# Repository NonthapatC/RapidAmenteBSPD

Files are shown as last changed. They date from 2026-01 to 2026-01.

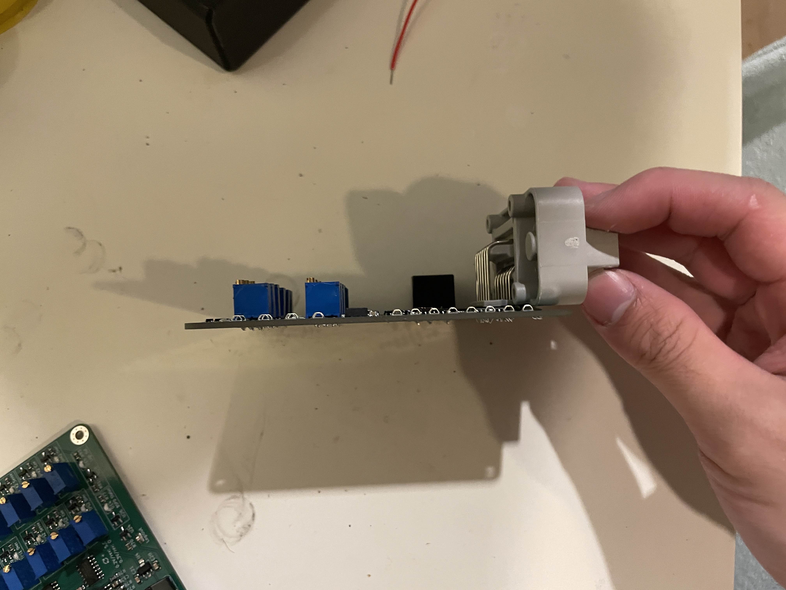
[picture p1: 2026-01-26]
----STEP_FILE----OPEN _PIC----/IMG_8208.jpg

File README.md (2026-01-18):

BSPD Logic;
TPS1 sense = TS1
TPS1 con = TC1
TPS1 over = TO1

TPS2 sense = TS2
TPS2 con = TC2
TPS2 over = TO2

BRK1 sense = BS1
BRK1 con = BC1
BRK1 over = BO1

BRK2 sense = BS2
BRK2 con = BC2
BRK2 over = BO2

(TS1+TS2)(BS1+BS2) -> 1000ms delay -> A

[(TC1)(TC2)(TO1+TO2)’(BC1)(BC2)(BO1+BO2)’]’ -> 100ms delay -> B

Final Logic; A+B -> latch R pin

Characteristic;
Normal:
BSPD status = 0v
BSPD status led = off
Latch R1/LogiOut led = off
Relay = com connected to NO; disconnected from NC

trip:
BSPD status = 12v
BSPD status led = on
Latch R1/LogiOut = on when trip condition satisfied
Relay = com connected to NC; disconnected from NO

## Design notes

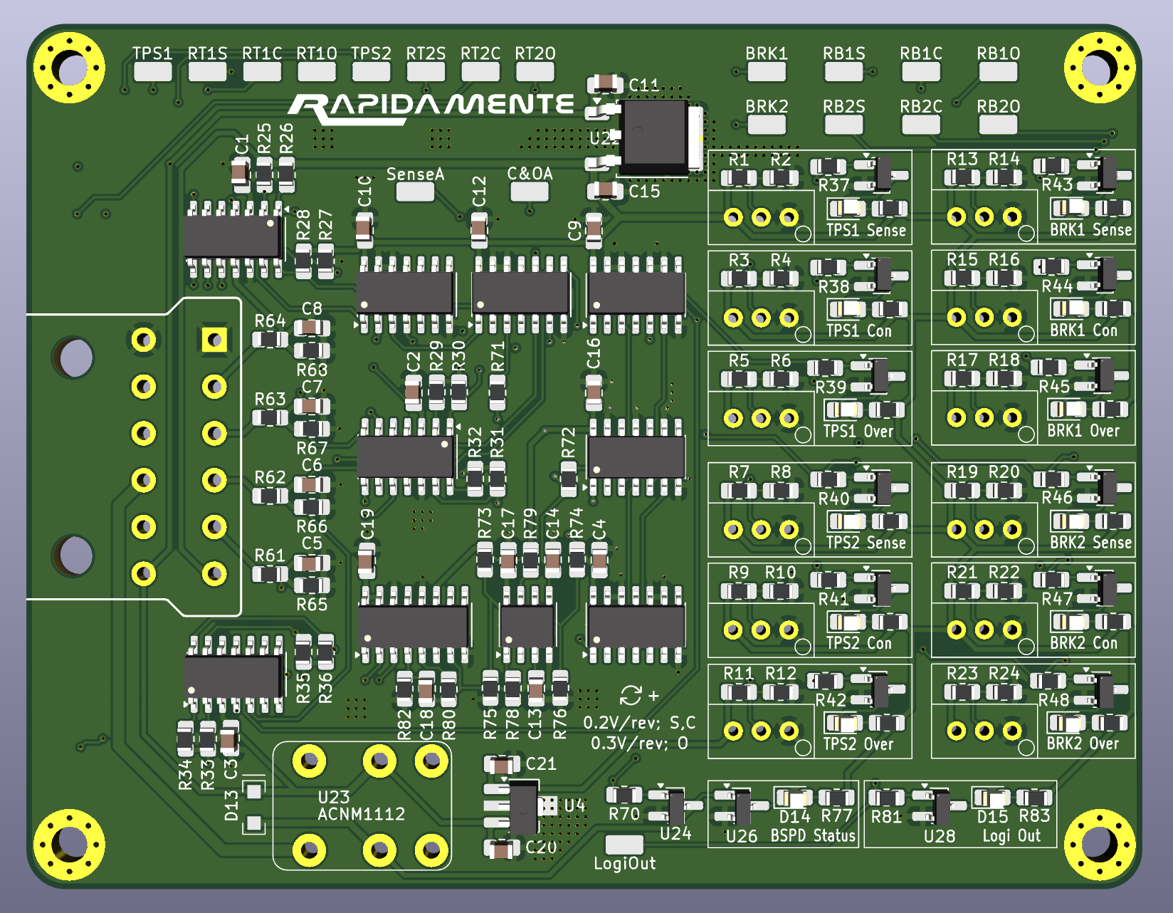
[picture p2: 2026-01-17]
Screenshot 2569-01-17 at 16.56.03.png

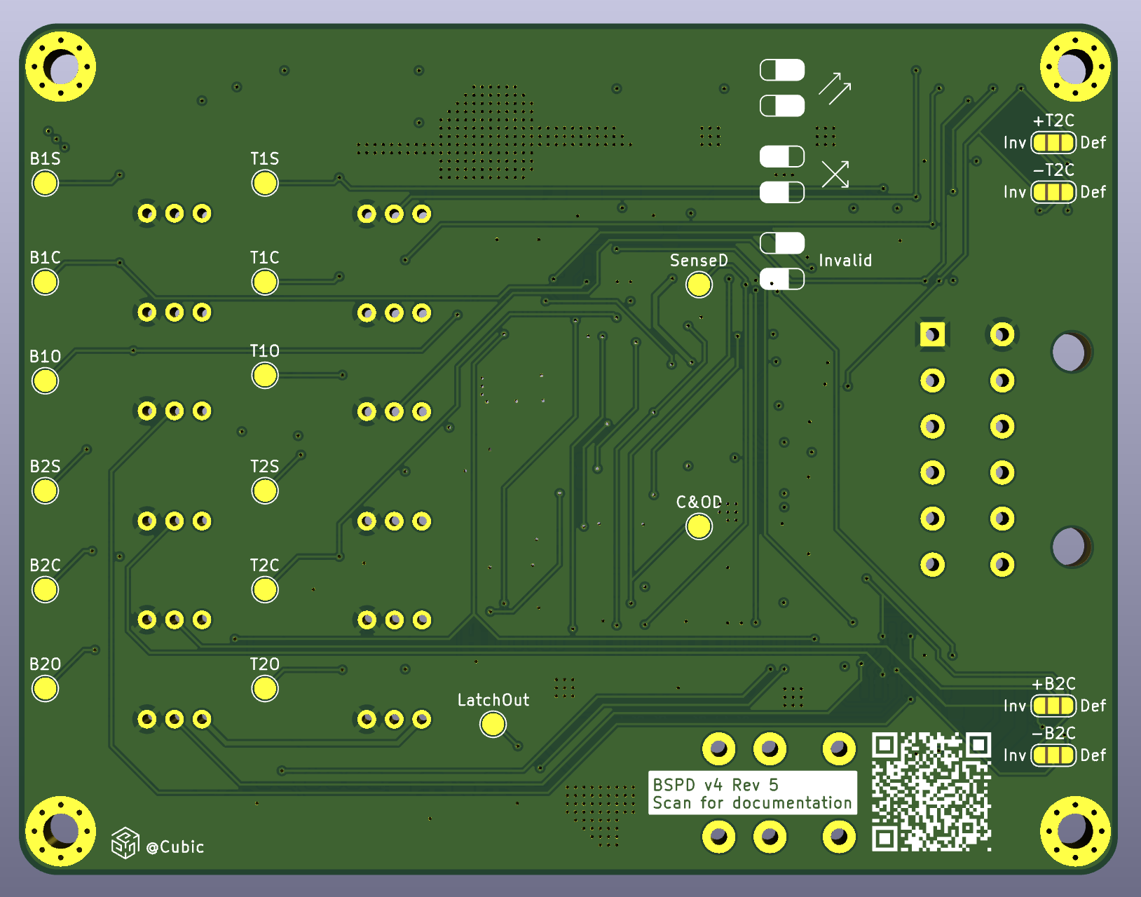
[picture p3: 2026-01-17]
Screenshot 2569-01-17 at 16.56.17.png

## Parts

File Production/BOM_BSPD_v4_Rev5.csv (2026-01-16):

Reference | Qty | Value | LCSC part number | Datasheet
C1,C2,C3,C4,C9,C10,C12,C15,C16,C17,C19,C21 | 12 | C0.1uF | C1711 | https://www.lcsc.com/product-detail/C1711.html?s_z=n_C1711
C5,C6,C7,C8 | 4 | C10nF | C1710 | https://www.lcsc.com/product-detail/C1710.html?s_z=n_C1710
C11,C20 | 2 | C0.33uF | C73142 | https://www.lcsc.com/product-detail/C73142.html?s_z=n_C73142
C13,C14,C18 | 3 | C10uF | C15850 | https://www.lcsc.com/product-detail/C15850.html?s_z=n_C15850
D1,D4,D7,D10 | 4 | YLED | C965814 | https://www.lcsc.com/product-detail/C965814.html
D2,D5,D8,D11 | 4 | GLED | C2986041 | https://www.lcsc.com/product-detail/C2986041.html
D3,D6,D9,D12,D14,D15 | 6 | RLED | C965812 | https://www.lcsc.com/product-detail/C965812.html?s_z=n_C965812
D13 | 1 | CRH01 | C2847411 | https://www.lcsc.com/product-detail/C2847411.html
J1 | 1 | DTM13-12PA | C17510017 | https://www.lcsc.com/product-detail/C17510017.html?s_z=n_dtm13-12PA
R25,R26,R27,R28,R29,R30,R31,R32,R33,R34,R35,R36,R65,R66,R67,R68,R73,R74,R78,R79,R80,R82 | 22 | R10K | C84376 | https://www.lcsc.com/product-detail/C84376.html?s_z=n_C84376
R37,R38,R39,R40,R41,R42,R43,R44,R45,R46,R47,R48,R81 | 13 | R150 | C17471 | https://www.lcsc.com/product-detail/C17471.html?s_z=n_C17471
R49,R51,R52,R54,R55,R57,R58,R60,R77,R83 | 10 | R200 | C2933534 | https://www.lcsc.com/product-detail/C2933534.html
R50,R53,R56,R59 | 4 | R82 | C2907287 | https://www.lcsc.com/product-detail/C2907287.html
R61,R62,R63,R64 | 4 | R1K | C17513 | https://www.lcsc.com/product-detail/C17513.html
R70 | 1 | R500 | C2828857 | https://www.lcsc.com/product-detail/C2828857.html?s_z=n_C2828857
R71 | 1 | R68K | C17801 | https://www.lcsc.com/product-detail/C17801.html?s_z=n_C17801
R72 | 1 | R6.8K | C114550 | https://www.lcsc.com/product-detail/C114550.html?s_z=n_C114550
R75,R76 | 2 | R22K | C114565 | https://www.lcsc.com/product-detail/C114565.html?s_z=n_C114565
RV1,RV2,RV3,RV4,RV5,RV6,RV7,RV8,RV9,RV10,RV11,RV12 | 12 | R_Potentiometer_Trim | C118954 | https://www.lcsc.com/product-detail/C118954.html?s_z=n_C118954
TP1,TP2,TP3,TP4,TP5,TP6,TP7,TP8,TP9,TP10,TP11,TP12,TP13,TP14,TP15,TP16,TP29,TP30,TP33 | 19 | TestHook | C5199798 | https://www.lcsc.com/product-detail/C5199798.html?s_z=n_C5199798
U1,U2,U3 | 3 | LM339 | C71036 | https://www.lcsc.com/product-detail/C71036.html?s_z=n_st
U4 | 1 | 78L08MG-AB3-R | C75495 | https://www.lcsc.com/product-detail/C75495.html
U5,U6,U7,U8,U9,U10,U11,U12,U13,U14,U15,U16,U26,U28 | 14 | 2N7002 | C65189 | https://www.lcsc.com/product-detail/C65189.html
U17 | 1 | 74HC08D | C5593 | https://www.lcsc.com/product-detail/C5593.html?s_z=n_74HC08
U18 | 1 | 74HC21D | C5617 | https://www.lcsc.com/product-detail/C5617.html
U19,U21 | 2 | 74HC32D | C5632 | https://www.lcsc.com/product-detail/C5632.html?s_z=n_C5632
U20 | 1 | 74HC04 | C5590 | https://www.lcsc.com/product-detail/C5590.html?s_z=n_C5590
U22 | 1 | L78M05ABDT-TR | C58069 | https://www.lcsc.com/product-detail/C58069.html
U23 | 1 | ACNM1112 | C5355536 | https://www.lcsc.com/product-detail/C5355536.html
U24 | 1 | IRLML2502TRPBF | C2589 | https://www.lcsc.com/product-detail/C2589.html
U25 | 1 | CD4043BDR | C40131 | https://www.lcsc.com/product-detail/C40131.html?s_z=n_CD4043B
U27 | 1 | LM393 | C32901 | https://www.lcsc.com/product-detail/C32901.html?s_z=n_C32901

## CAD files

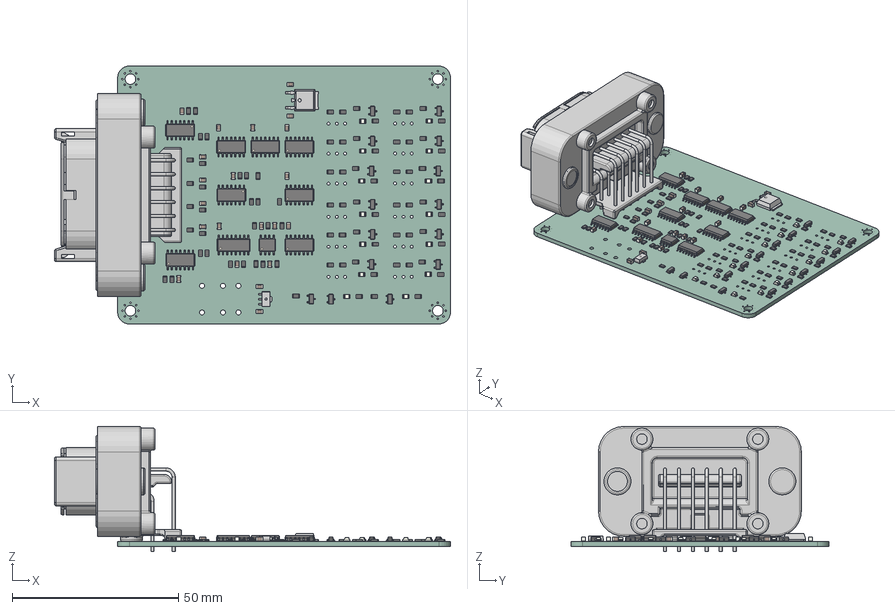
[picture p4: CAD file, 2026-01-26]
----STEP_FILE----OPEN _PIC----/27JAN_BSPD v4 Rev 5.step
119.0 x 77.5 x 37.6 mm
R_0805_2012Metric x 82
LED_0805_2012Metric x 14
SOIC-14_3.9x8.7mm_P1.27mm x 8
27JAN_BSPD v4 Rev 5 1.7.1
C_0805_2012Metric x 21
SOT-23 x 15
SOIC-8_3.9x4.9mm_P1.27mm
27JAN_BSPD v4 Rev 5 1.90.1
SOIC-16_3.9x9.9mm_P1.27mm
BSPD v4 Rev 5_PCB
C-DTM13-12PA

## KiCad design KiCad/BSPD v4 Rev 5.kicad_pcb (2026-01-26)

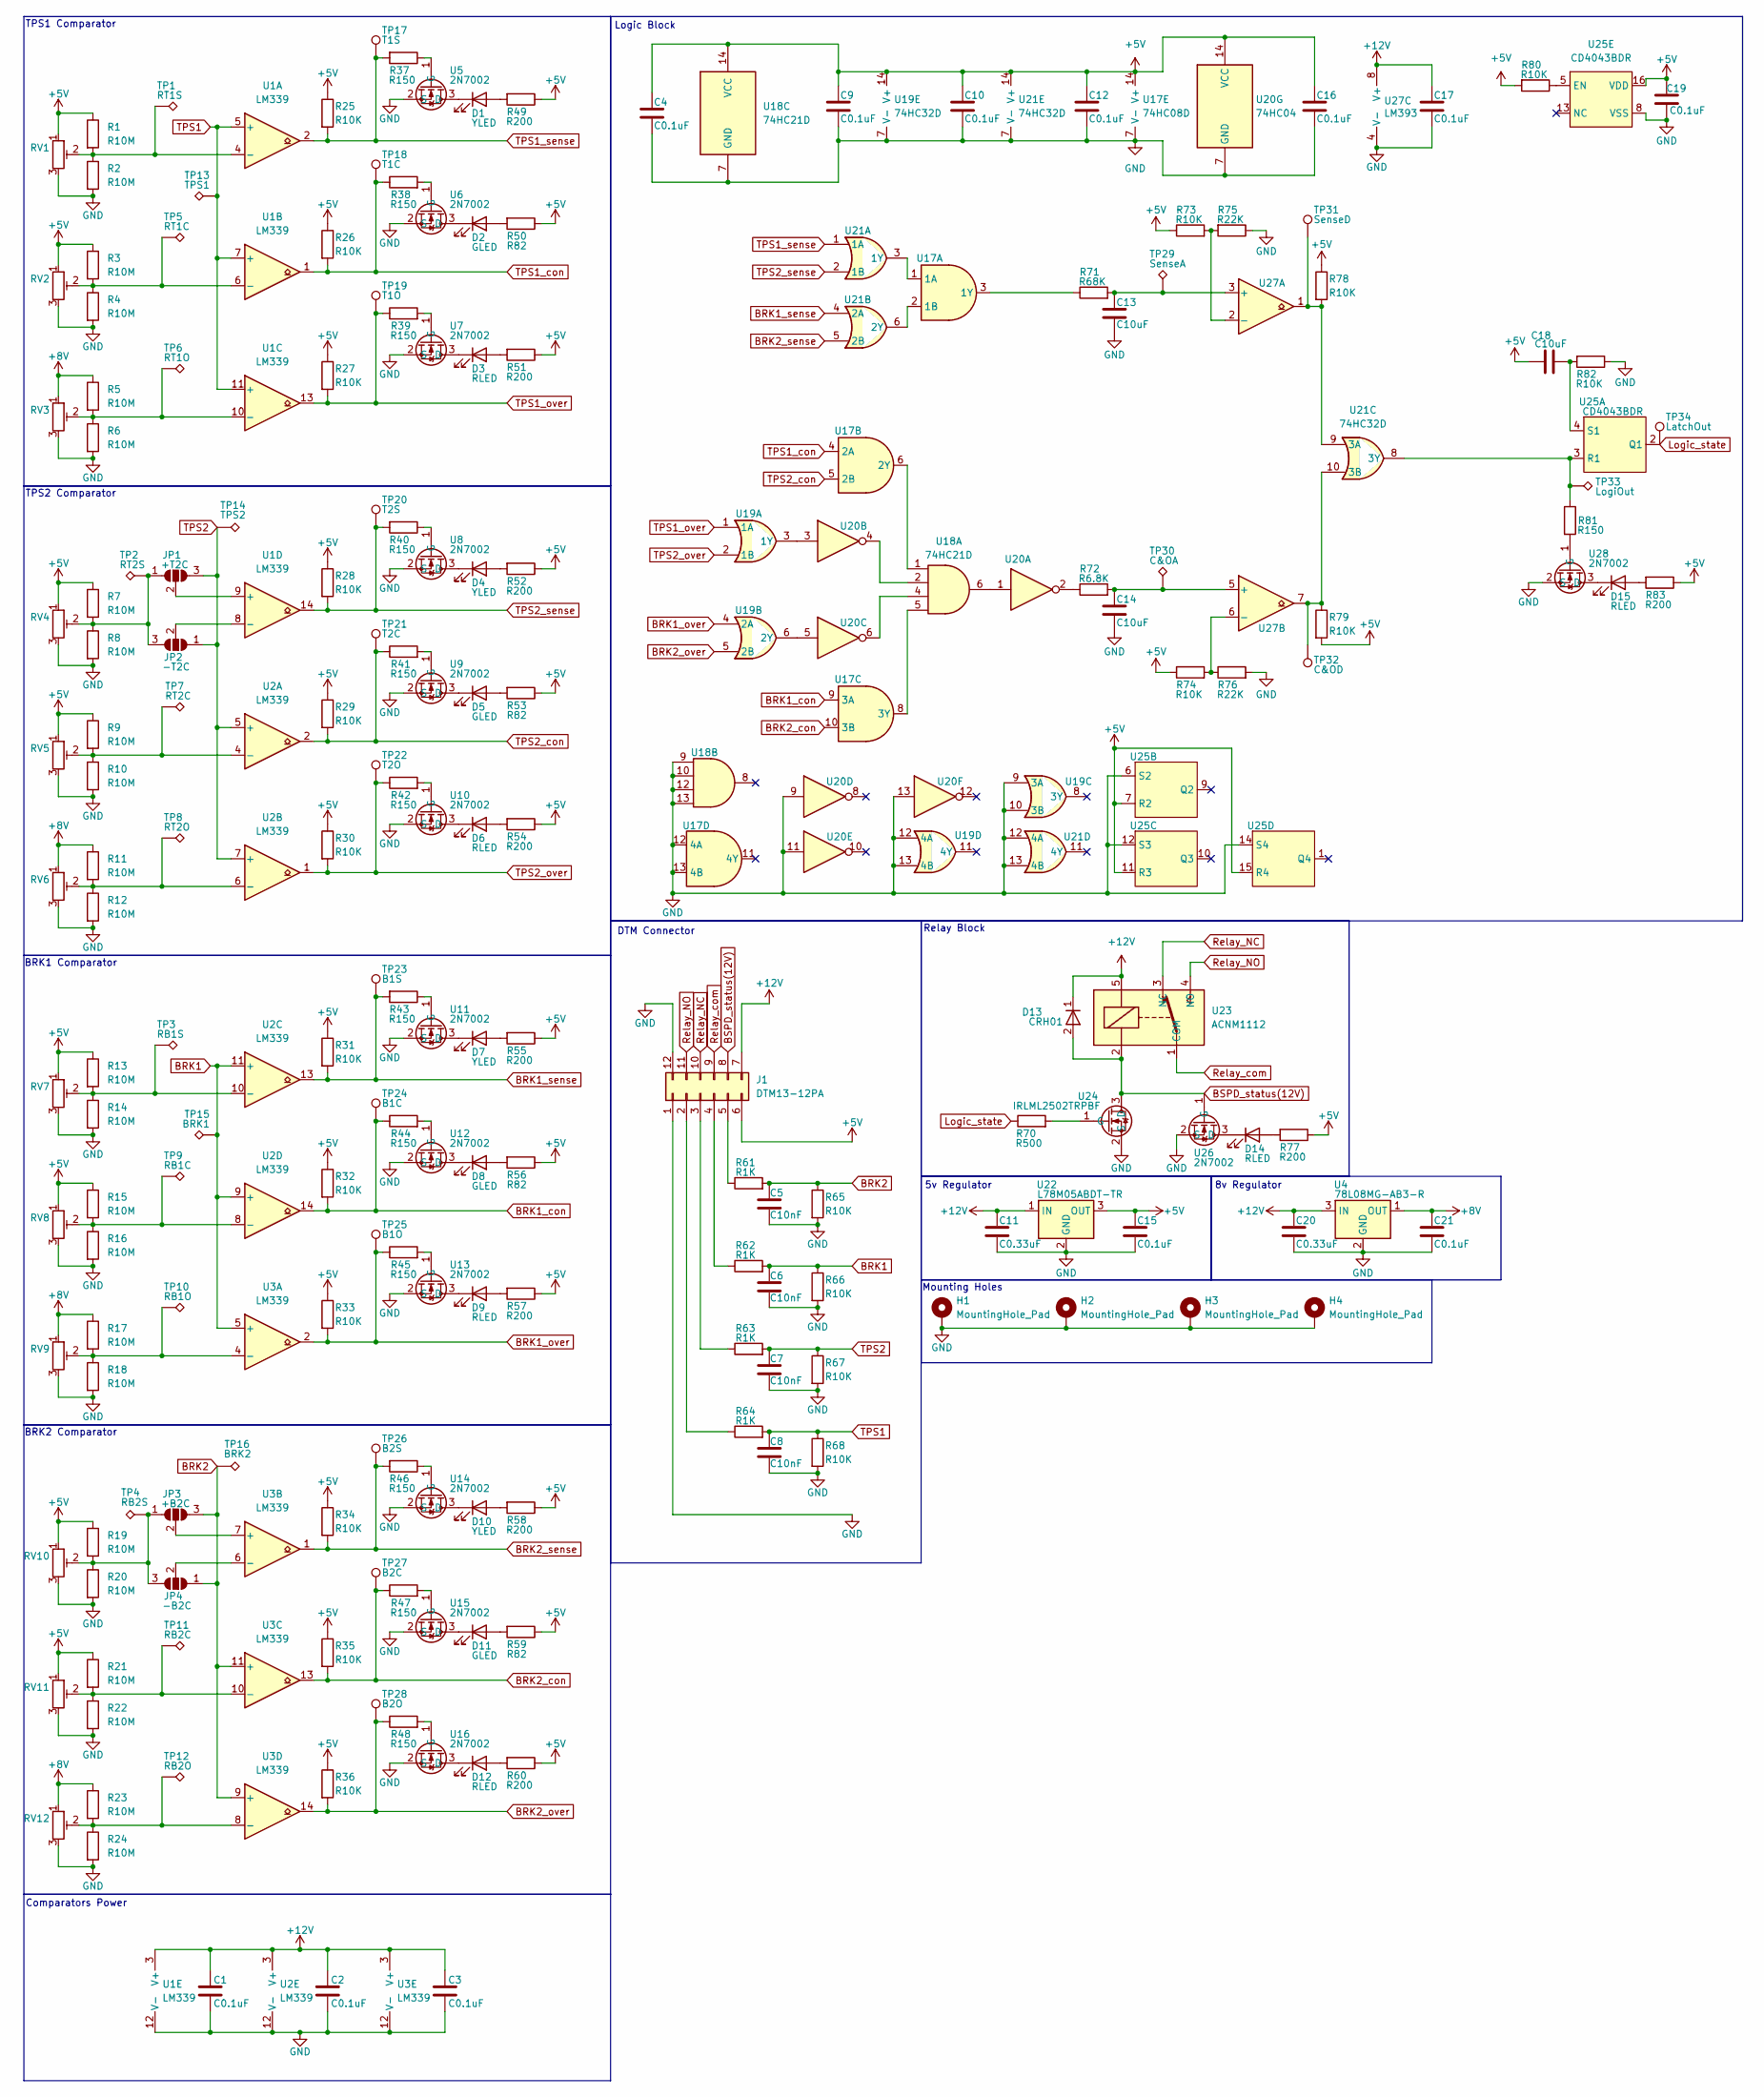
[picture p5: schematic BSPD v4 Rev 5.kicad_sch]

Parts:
C1, C2, C3, C4, C9, C10, C12, C15, C16, C17, C19, C21: C0.1uF; C_0805_2012Metric_Pad1.18x1.45mm_HandSolder
C5, C6, C7, C8: C10nF; C_0805_2012Metric_Pad1.18x1.45mm_HandSolder
C11, C20: C0.33uF; C_0805_2012Metric_Pad1.18x1.45mm_HandSolder
C13, C14, C18: C10uF; C_0805_2012Metric_Pad1.18x1.45mm_HandSolder
D1, D4, D7, D10: YLED; LED_0805_2012Metric_Pad1.15x1.40mm_HandSolder
D2, D5, D8, D11: GLED; LED_0805_2012Metric_Pad1.15x1.40mm_HandSolder
D3, D6, D9, D12, D14, D15: RLED; LED_0805_2012Metric_Pad1.15x1.40mm_HandSolder
D13: CRH01; S-FLAT(1.6x3.5)
H1, H2, H3, H4: MountingHole_Pad; MountingHole_3.2mm_M3_Pad_Via
J1: DTM13-12PA
JP1, JP2, JP3, JP4: SolderJumper_3_Open; SolderedJumper 3P
R1, R2, R3, R4, R5, R6, R7, R8, R9, R10, R11, R12, R13, R14, R15, R16, R17, R18, R19, R20, R21, R22, R23, R24: R10M; R_0805_2012Metric_Pad1.20x1.40mm_HandSolder
R25, R26, R27, R28, R29, R30, R31, R32, R33, R34, R35, R36, R65, R66, R67, R68, R73, R74, R78, R79, R80, R82: R10K; R_0805_2012Metric_Pad1.20x1.40mm_HandSolder
R37, R38, R39, R40, R41, R42, R43, R44, R45, R46, R47, R48, R81: R150; R_0805_2012Metric_Pad1.20x1.40mm_HandSolder
R49, R51, R52, R54, R55, R57, R58, R60, R77, R83: R200; R_0805_2012Metric_Pad1.20x1.40mm_HandSolder
R50, R53, R56, R59: R82; R_0805_2012Metric_Pad1.20x1.40mm_HandSolder
R61, R62, R63, R64: R1K; R_0805_2012Metric_Pad1.20x1.40mm_HandSolder
R70: R500; R_0805_2012Metric_Pad1.20x1.40mm_HandSolder
R71: R68K; R_0805_2012Metric_Pad1.20x1.40mm_HandSolder
R72: R6.8K; R_0805_2012Metric_Pad1.20x1.40mm_HandSolder
R75, R76: R22K; R_0805_2012Metric_Pad1.20x1.40mm_HandSolder
RV1, RV2, RV3, RV4, RV5, RV6, RV7, RV8, RV9, RV10, RV11, RV12: R_Potentiometer_Trim; SIP-3P tirmpot
TP1, TP2, TP3, TP4, TP5, TP6, TP7, TP8, TP9, TP10, TP11, TP12, TP13, TP14, TP15, TP16, TP29, TP30, TP33: TestHook; ronghe RH-5015
TP17, TP18, TP19, TP20, TP21, TP22, TP23, TP24, TP25, TP26, TP27, TP28, TP31, TP32, TP34: Testpad; Custom_Testpad
U1, U2, U3: LM339; SOIC-14_3.9x8.7mm_P1.27mm
U4: 78L08MG-AB3-R; SOT-89-3_Handsoldering
U5, U6, U7, U8, U9, U10, U11, U12, U13, U14, U15, U16, U26, U28: 2N7002; SOT-23_Handsoldering
U17: 74HC08D; SOIC-14_3.9x8.7mm_P1.27mm
U18: 74HC21D; SOIC-14_3.9x8.7mm_P1.27mm
U19, U21: 74HC32D; SOIC-14_3.9x8.7mm_P1.27mm
U20: 74HC04; SOIC-14_3.9x8.7mm_P1.27mm
U22: L78M05ABDT-TR; TO-252-2
U23: ACNM1112; PANASONIC ACNM1112
U24: IRLML2502TRPBF; SOT-23_Handsoldering
U25: CD4043BDR; SOIC-16_3.9x9.9mm_P1.27mm
U27: LM393; SOIC-8_3.9x4.9mm_P1.27mm

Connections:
+5V: C4.1, C9.1, C10.1, C12.1, C15.1, C16.1, C18.1, C19.1, J1.6, R1.1, R3.1, R7.1, R9.1, R13.1, R15.1, R19.1, R21.1, R25.1, R26.1, R27.1, R28.1, R29.1, R30.1, R31.1, R32.1, R33.1, R34.1, R35.1, R36.1, R49.1, R50.1, R51.1, R52.1, R53.1, R54.1, R55.1, R56.1, R57.1, R58.1, R59.1, R60.1, R73.1, R74.1, R77.1, R78.1, R79.2, R80.2, R83.1, RV1.1, RV2.1, RV4.1, RV5.1, RV7.1, RV8.1, RV10.1, RV11.1, U17.14 (V+), U18.14 (VCC), U19.14 (V+), U20.14 (VCC), U21.14 (V+), U22.3 (OUT), U25.7 (R2), U25.11 (R3), U25.15 (R4), U25.16 (VDD)
+8V: C21.1, R5.1, R11.1, R17.1, R23.1, RV3.1, RV6.1, RV9.1, RV12.1, U4.1 (OUT)
+12V: C1.1, C2.1, C3.1, C11.1, C17.1, C20.1, D13.1, J1.7, U1.3 (V+), U2.3 (V+), U3.3 (V+), U4.3 (IN), U22.1 (IN), U23.5, U27.8 (V+)
BRK1: C6.1, R62.2, R66.1, TP15.1, U2.9 (+), U2.11 (+), U3.5 (+)
BRK1_con: R32.2, R44.1, TP24.1, U2.14, U17.9 (3A)
BRK1_over: R33.2, R45.1, TP25.1, U3.2, U19.4 (2A)
BRK1_sense: R31.2, R43.2, TP23.1, U2.13, U21.4 (2A)
BRK2: C5.1, JP3.3 (B), JP4.1 (A), R61.2, R65.1, TP16.1, U3.9 (+), U3.11 (+)
BRK2_con: R35.2, R47.1, TP27.1, U3.13, U17.10 (3B)
BRK2_over: R36.2, R48.1, TP28.1, U3.14, U19.5 (2B)
BRK2_sense: R34.2, R46.2, TP26.1, U3.1, U21.5 (2B)
BSPD_status(12V): D13.2, J1.8, U23.2, U24.3 (D), U26.1 (G)
GND: C1.2, C2.2, C3.2, C4.2, C5.2, C6.2, C7.2, C8.2, C9.2, C10.2, C11.2, C12.2, C13.2, C14.2, C15.2, C16.2, C17.2, C19.2, C20.2, C21.2, H1.1, H2.1, H3.1, H4.1, J1.1, J1.12, R2.2, R4.2, R6.2, R8.2, R10.2, R12.2, R14.2, R16.2, R18.2, R20.2, R22.2, R24.2, R65.2, R66.2, R67.2, R68.2, R75.1, R76.2, R82.1, RV1.3, RV2.3, RV3.3, RV4.3, RV5.3, RV6.3, RV7.3, RV8.3, RV9.3, RV10.3, RV11.3, RV12.3, U1.12 (V-), U2.12 (V-), U3.12 (V-), U4.2 (GND), U5.2 (S), U6.2 (S), U7.2 (S), U8.2 (S), U9.2 (S), U10.2 (S), U11.2 (S), U12.2 (S), U13.2 (S), U14.2 (S), U15.2 (S), U16.2 (S), U17.7 (V-), U17.12 (4A), U17.13 (4B), U18.7 (GND), U18.9, U18.10, U18.12, U18.13, U19.7 (V-), U19.9 (3A), U19.10 (3B), U19.12 (4A), U19.13 (4B), U20.7 (GND), U20.9, U20.11, U20.13, U21.7 (V-), U21.12 (4A), U21.13 (4B), U22.2 (GND), U24.2 (S), U25.6 (S2), U25.8 (VSS), U25.12 (S3), U25.14 (S4), U26.2 (S), U27.4 (V-), U28.2 (S)
Logic_state: R70.1, TP34.1, U25.2 (Q1)
unnamed: D1.2 (A), R49.2
unnamed: D1.1 (K), U5.3 (D)
unnamed: D2.2 (A), R50.2
unnamed: D2.1 (K), U6.3 (D)
unnamed: D3.2 (A), R51.2
unnamed: D3.1 (K), U7.3 (D)
unnamed: D4.2 (A), R52.2
unnamed: D4.1 (K), U8.3 (D)
unnamed: D5.2 (A), R53.2
unnamed: D5.1 (K), U9.3 (D)
unnamed: D6.2 (A), R54.2
unnamed: D6.1 (K), U10.3 (D)
unnamed: D7.2 (A), R55.2
unnamed: D7.1 (K), U11.3 (D)
unnamed: D8.2 (A), R56.2
unnamed: D8.1 (K), U12.3 (D)
unnamed: D9.2 (A), R57.2
unnamed: D9.1 (K), U13.3 (D)
unnamed: D10.2 (A), R58.2
unnamed: D10.1 (K), U14.3 (D)
unnamed: D11.2 (A), R59.2
unnamed: D11.1 (K), U15.3 (D)
unnamed: D12.2 (A), R60.2
unnamed: D12.1 (K), U16.3 (D)
unnamed: D14.2 (A), R77.2
unnamed: D14.1 (K), U26.3 (D)
unnamed: D15.2 (A), R83.2
unnamed: D15.1 (K), U28.3 (D)
unnamed: J1.2, R64.1
unnamed: J1.3, R63.1
unnamed: J1.4, R62.1
unnamed: J1.5, R61.1
unnamed: JP1.1 (A), JP2.3 (B), R7.2, R8.1, RV4.2, TP2.1
unnamed: JP1.2 (C), U1.9 (+)
unnamed: JP2.2 (C), U1.8 (-)
unnamed: JP3.1 (A), JP4.3 (B), R19.2, R20.1, RV10.2, TP4.1
unnamed: JP3.2 (C), U3.7 (+)
unnamed: JP4.2 (C), U3.6 (-)
unnamed: R72.1, U20.2
unnamed: R1.2, R2.1, RV1.2, TP1.1, U1.4 (-)
unnamed: R3.2, R4.1, RV2.2, TP5.1, U1.6 (-)
unnamed: R5.2, R6.1, RV3.2, TP6.1, U1.10 (-)
unnamed: R9.2, R10.1, RV5.2, TP7.1, U2.4 (-)
unnamed: R11.2, R12.1, RV6.2, TP8.1, U2.6 (-)
unnamed: R13.2, R14.1, RV7.2, TP3.1, U2.10 (-)
unnamed: R15.2, R16.1, RV8.2, TP9.1, U2.8 (-)
unnamed: R17.2, R18.1, RV9.2, TP10.1, U3.4 (-)
unnamed: R21.2, R22.1, RV11.2, TP11.1, U3.10 (-)
unnamed: R23.2, R24.1, RV12.2, TP12.1, U3.8 (-)
unnamed: R37.1, U5.1 (G)
unnamed: R38.2, U6.1 (G)
unnamed: R39.2, U7.1 (G)
unnamed: R40.1, U8.1 (G)
unnamed: R41.2, U9.1 (G)
unnamed: R42.2, U10.1 (G)
unnamed: R43.1, U11.1 (G)
unnamed: R44.2, U12.1 (G)
unnamed: R45.2, U13.1 (G)
unnamed: R46.1, U14.1 (G)
unnamed: R47.2, U15.1 (G)
unnamed: R48.2, U16.1 (G)
unnamed: U17.1 (1A), U21.3 (1Y)
unnamed: U17.2 (1B), U21.6 (2Y)
unnamed: R71.1, U17.3 (1Y)
unnamed: U17.6 (2Y), U18.1
unnamed: U17.8 (3Y), U18.5
unnamed: U18.2, U20.4
unnamed: U18.4, U20.6
unnamed: U18.6, U20.1
unnamed: U19.3 (1Y), U20.3
unnamed: U19.6 (2Y), U20.5
unnamed: R78.2, TP31.1, U21.9 (3A), U27.1
unnamed: R79.1, TP32.1, U21.10 (3B), U27.7
unnamed: R81.1, TP33.1, U21.8 (3Y), U25.3 (R1)
unnamed: R70.2, U24.1 (G)
unnamed: C18.2, R82.2, U25.4 (S1)
unnamed: R80.1, U25.5 (EN)
unnamed: C13.1, R71.2, TP29.1, U27.3 (+)
unnamed: R73.2, R75.2, U27.2 (-)
unnamed: C14.1, R72.2, TP30.1, U27.5 (+)
unnamed: R74.2, R76.1, U27.6 (-)
unnamed: R81.2, U28.1 (G)
Relay_NC: J1.10, U23.3 (NC)
Relay_NO: J1.11, U23.4 (NO)
Relay_com: J1.9, U23.1 (COM)
TPS1: C8.1, R64.2, R68.1, TP13.1, U1.5 (+), U1.7 (+), U1.11 (+)
TPS1_con: R26.2, R38.1, TP18.1, U1.1, U17.4 (2A)
TPS1_over: R27.2, R39.1, TP19.1, U1.13, U19.1 (1A)
TPS1_sense: R25.2, R37.2, TP17.1, U1.2, U21.1 (1A)
TPS2: C7.1, JP1.3 (B), JP2.1 (A), R63.2, R67.1, TP14.1, U2.5 (+), U2.7 (+)
TPS2_con: R29.2, R41.1, TP21.1, U2.2, U17.5 (2B)
TPS2_over: R30.2, R42.1, TP22.1, U2.1, U19.2 (1B)
TPS2_sense: R28.2, R40.2, TP20.1, U1.14, U21.2 (1B)

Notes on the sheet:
8v Regulator
TPS1 Comparator
Relay Block
DTM Connector
5v Regulator
TPS2 Comparator
BRK2 Comparator
Logic Block
Comparators Power
Mounting Holes
BRK1 Comparator

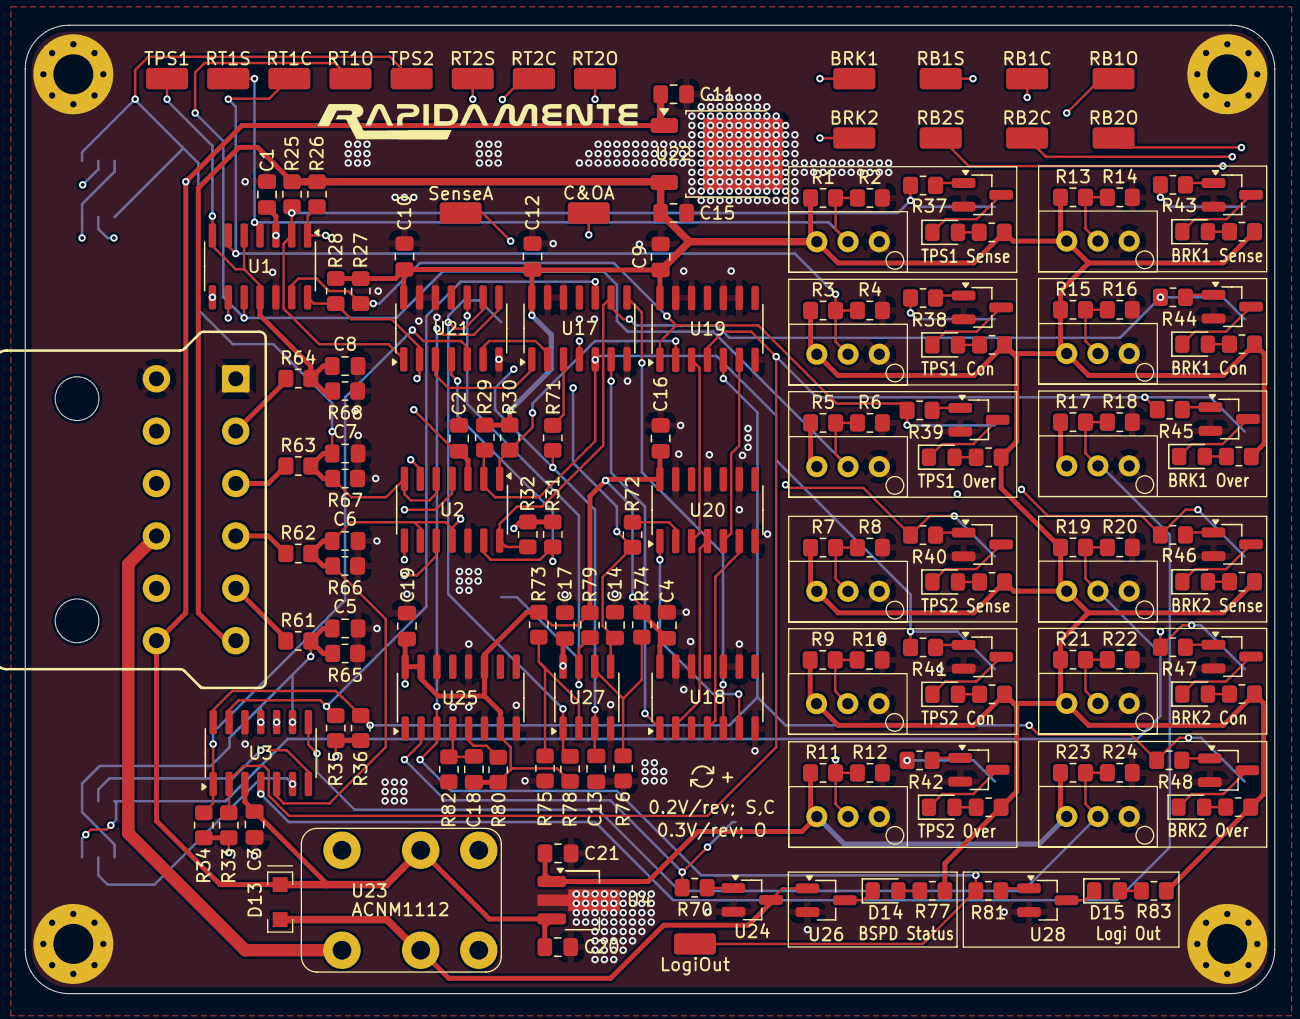
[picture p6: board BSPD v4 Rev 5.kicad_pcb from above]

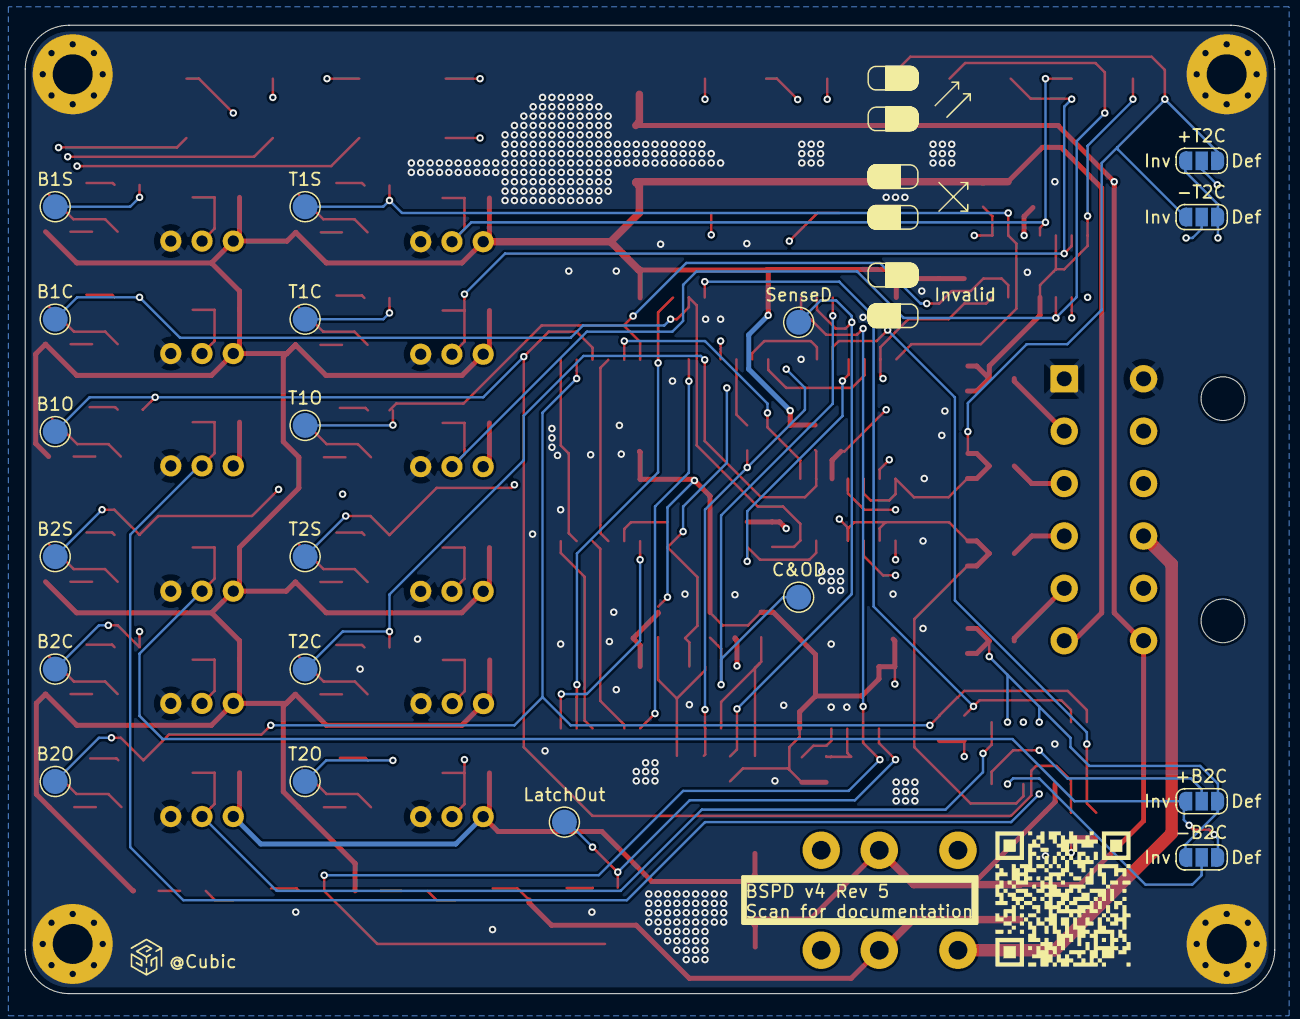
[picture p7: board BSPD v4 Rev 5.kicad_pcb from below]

Board: 4 copper layers, 100.0 x 77.5 mm, 201 parts (19 on the bottom side), 107 nets.

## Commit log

2025-12-22 Changed DTM NPTH size
    [BSPD v4 Rev 5-B_Mask.gbr, BSPD v4 Rev 5-B_Paste.gbr, BSPD v4 Rev 5-B_Silkscreen.gbr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]
2025-12-22 moved lm393 to 12v
    [BSPD v4 Rev 5-B_Mask.gbr, BSPD v4 Rev 5-B_Paste.gbr, BSPD v4 Rev 5-B_Silkscreen.gbr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]
2026-01-08 differentail TPS, stable Over ref voltage
    [BOM_BSPD v4 Rev 5.csv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]
2026-01-16 Added support for differential input, Changed LED colors and resistor
    [BOM_BSPD_v4_Rev5.csv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]
2026-01-17 Updated Silkscreen
    [BSPD v4 Rev 5-B_Mask.gbr, BSPD v4 Rev 5-B_Paste.gbr, BSPD v4 Rev 5-B_Silkscreen.gbr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]
2026-01-18 Fixed, swapped relay symbol swapped NC and NO (same wiring maintained)
    [BSPD v4 Rev 5.kicad_pcb, BSPD v4 Rev 5.kicad_sch]
2026-01-18 Added read me with corrected relay naming
2026-01-26 added step file]
    [27JAN_BSPD v4 Rev 5.step]
2026-01-26 fixed fuckup
    [BSPD v4 Rev 5-B_Mask.gbr, BSPD v4 Rev 5-B_Paste.gbr, BSPD v4 Rev 5-B_Silkscreen.gbr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]
